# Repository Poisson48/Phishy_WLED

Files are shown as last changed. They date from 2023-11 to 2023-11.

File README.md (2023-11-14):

Phishy_WLED is a simple board to drive LED with the help of WLED software. It's based on esp32, it's fully open-source and i will probably sell some boards on etsy soon.

## Features
- RGBWWW LED strip support
- WS2182B ( or any ws18 someting ) LED strip support
- input from 5V to 60V
- pulled up inputs

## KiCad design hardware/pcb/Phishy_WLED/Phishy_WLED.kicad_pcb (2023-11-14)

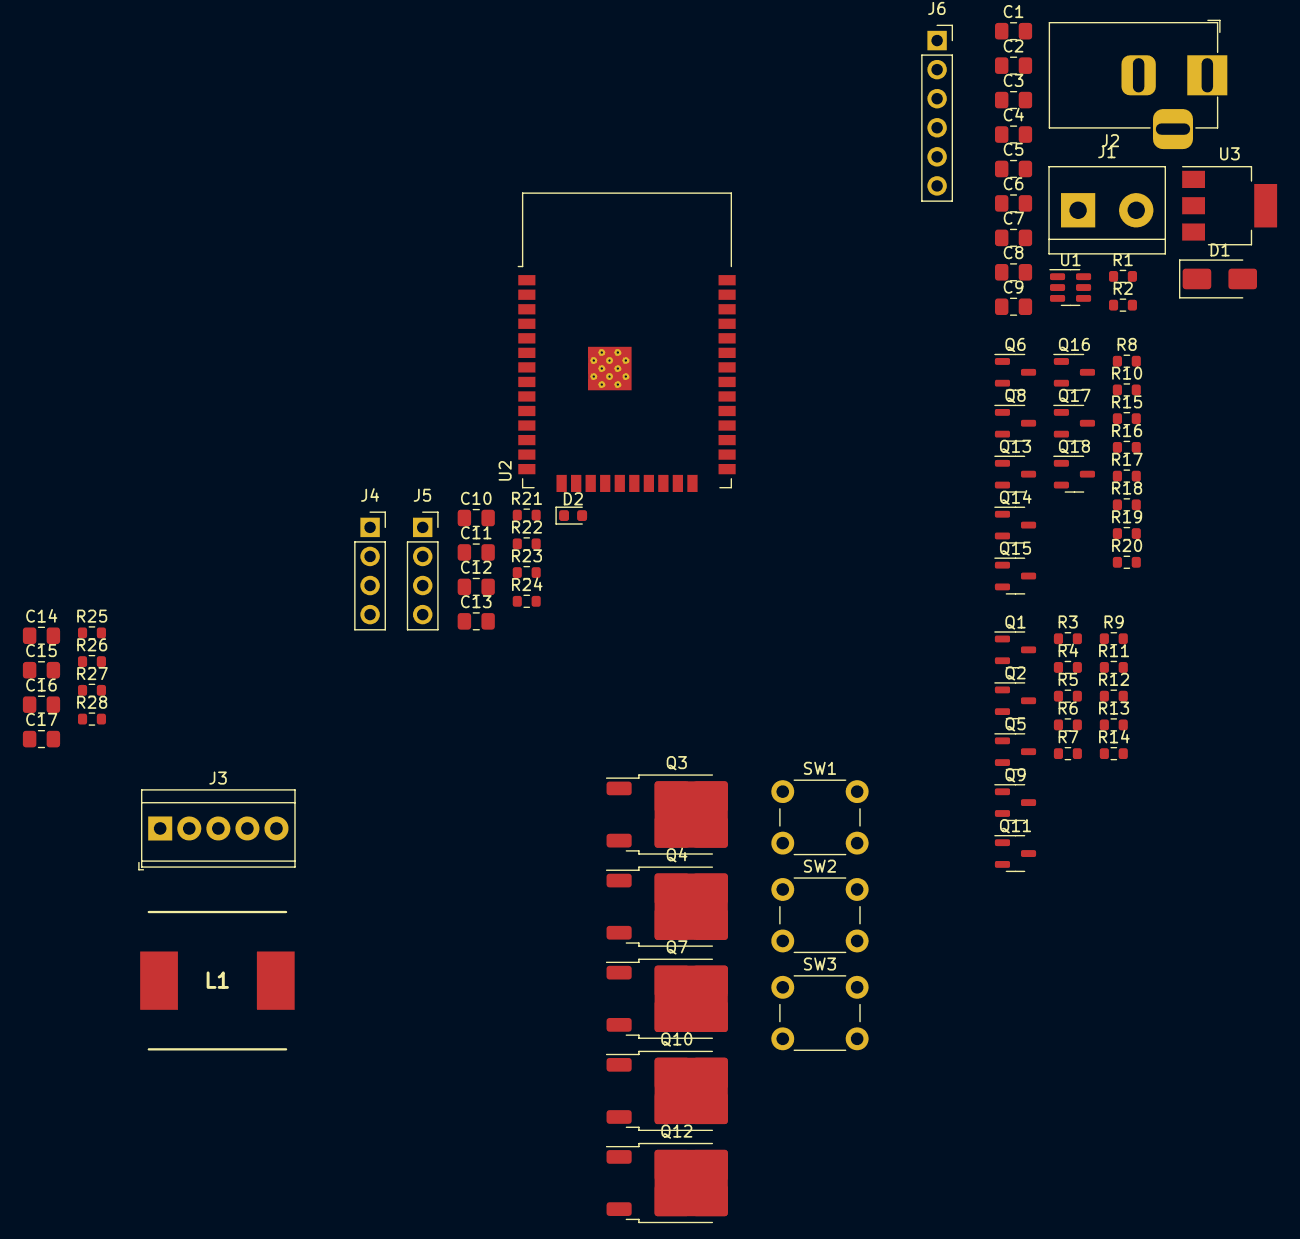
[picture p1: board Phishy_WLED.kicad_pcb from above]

Board: 2 copper layers, 78 parts (0 on the bottom side), 54 nets, no tracks yet.

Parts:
C1, C3, C5, C6, C8, C10, C13, C14, C15, C16, C17: 100nF; C_0805_2012Metric_Pad1.18x1.45mm_HandSolder
C2, C4, C7, C9, C11, C12: 10uF; C_0805_2012Metric_Pad1.18x1.45mm_HandSolder
D1: D_Schottky; D_SMA
D2: LED; LED_0603_1608Metric
J1: Screw_Terminal_01x02; TerminalBlock_bornier-2_P5.08mm
J2: Barrel_Jack_Switch; BarrelJack_Horizontal
J3: Screw_Terminal_01x05; TerminalBlock_TE_282834-5_1x05_P2.54mm_Horizontal
J4, J5: Screw_Terminal_01x04; PinSocket_1x04_P2.54mm_Vertical
J6: Conn_01x06; PinSocket_1x06_P2.54mm_Vertical
L1: 22uH; INDPM120120X800N
Q1, Q2, Q5, Q6, Q8, Q9, Q11, Q15, Q16: 2N7002L; SOT-23-3
Q3, Q4, Q7, Q10, Q12: IRFR1205TRPBF; TO-252-2
Q13, Q14, Q17, Q18: BSS138; SOT-23-3
R1, R2: R; R_0603_1608Metric
R3, R4, R7, R8, R11, R13, R15, R17, R18, R21, R22, R24, R25, R26, R27, R28: 10k; R_0603_1608Metric
R5, R6, R9, R10, R12, R14, R16, R19, R20, R23: 1k; R_0603_1608Metric
SW1, SW2, SW3: SW_Push; SW_PUSH_6mm_H5mm
U1: LMR16006YQ; SOT-23-6
U2: ESP32-WROOM-32D
U3: LM7805MP; SOT-223-3_TabPin2

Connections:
+3.3V: C4.1, C5.1, C10.1, C11.1, J6.3, L1.2, R1.1, R21.2, R22.2, R24.2, R25.2, R26.2, R27.2, R28.2, U2.2 (VDD)
+5V: C8.1, C9.1, R10.2, R16.2, R19.2, R20.2, U3.3 (OUT)
/drivers/in_B: R7.1, U2.28 (IO17)
/drivers/in_G: R4.1, U2.27 (IO16)
/drivers/in_R: R3.1, U2.16 (IO13)
/drivers/in_W: R11.1, U2.30 (IO18)
/drivers/in_WW: R13.1, U2.31 (IO19)
/drivers/out_B: J3.3, Q7.2 (D)
/drivers/out_G: J3.2, Q4.2 (D)
/drivers/out_R: J3.1, Q3.2 (D)
/drivers/out_W: J3.4, Q10.2 (D)
/drivers/out_WW: J3.5, Q12.2 (D)
/pulls_ups/pull_input_ext_1: C14.1, J5.1, R25.1, U2.11 (IO26)
/pulls_ups/pull_input_ext_2: C15.1, J5.2, R26.1, U2.12 (IO27)
/pulls_ups/pull_input_ext_3: C16.1, J5.3, R27.1, U2.8 (IO32)
/pulls_ups/pull_input_ext_4: C17.1, J5.4, R28.1, U2.9 (IO33)
/ws28xx_LEDs/in_DATA_1: R8.1, U2.33 (IO21)
/ws28xx_LEDs/in_DATA_2: R15.1, U2.36 (IO22)
/ws28xx_LEDs/in_DATA_3: R17.1, U2.37 (IO23)
/ws28xx_LEDs/in_DATA_4: R18.1, U2.10 (IO25)
/ws28xx_LEDs/out_DATA_1: J4.1, Q13.3 (D)
/ws28xx_LEDs/out_DATA_2: J4.2, Q14.3 (D)
/ws28xx_LEDs/out_DATA_3: J4.3, Q17.3 (D)
/ws28xx_LEDs/out_DATA_4: J4.4, Q18.3 (D)
EN: C12.1, J6.5, R21.1, SW2.2, U2.3 (EN)
unnamed: C3.2, D1.1 (K), L1.1, U1.6 (SW)
unnamed: D2.2 (A), R23.2
unnamed: Q1.2 (B), R3.2
unnamed: Q1.1 (C), Q3.1 (G), R5.1
unnamed: Q2.2 (B), R4.2
unnamed: Q2.1 (C), Q4.1 (G), R6.1
unnamed: Q5.2 (B), R7.2
unnamed: Q5.1 (C), Q7.1 (G), R9.1
unnamed: Q6.2 (B), R8.2
unnamed: Q8.2 (B), R15.2
unnamed: Q9.2 (B), R11.2
unnamed: Q9.1 (C), Q10.1 (G), R12.1
unnamed: Q11.2 (B), R13.2
unnamed: Q11.1 (C), Q12.1 (G), R14.1
unnamed: Q6.1 (C), Q13.1 (G), R10.1
unnamed: Q8.1 (C), Q14.1 (G), R16.1
unnamed: Q15.2 (B), R17.2
unnamed: Q15.1 (C), Q17.1 (G), R19.1
unnamed: Q16.2 (B), R18.2
unnamed: Q16.1 (C), Q18.1 (G), R20.1
unnamed: C3.1, U1.1 (CB)
unnamed: R1.2, R2.1, U1.3 (FB)
unnamed: R22.1, SW1.1, U2.25 (IO0)
unnamed: R23.1, U2.24 (IO2)
unnamed: C13.1, R24.1, SW3.1, U2.26 (IO4)
RST: C1.2, C2.2, C4.2, C5.2, C6.2, C7.2, C8.2, C9.2, C10.2, C11.2, C12.2, C13.2, C14.2, C15.2, C16.2, C17.2, D1.2 (A), D2.1 (K), J1.2, J2.2, J2.3, J6.4, J6.6, Q1.3 (E), Q2.3 (E), Q3.3 (S), Q4.3 (S), Q5.3 (E), Q6.3 (E), Q7.3 (S), Q8.3 (E), Q9.3 (E), Q10.3 (S), Q11.3 (E), Q12.3 (S), Q13.2 (S), Q14.2 (S), Q15.3 (E), Q16.3 (E), Q17.2 (S), Q18.2 (S), R2.2, SW1.2, SW2.1, SW3.2, U1.2 (GND), U2.1 (GND), U2.15 (GND), U2.38 (GND), U2.39 (GND), U3.2 (GND)
RX: J6.2, U2.34 (RXD0/IO3)
TX: J6.1, U2.35 (TXD0/IO1)
VCC: C1.1, C2.1, C6.1, C7.1, J1.1, J2.1, R5.2, R6.2, R9.2, R12.2, R14.2, U1.5 (VIN), U3.1 (IN)

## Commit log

2023-11-14 basic schematic
    the basic schematic is finished, need to add the footprints and begin the placement
    [Phishy_WLED.kicad_pcb, Phishy_WLED.kicad_sch, alim.kicad_sch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]
2023-11-14 footprints added !
    all the footprints are here
    [Phishy_WLED.kicad_pcb, Phishy_WLED.kicad_sch, alim.kicad_sch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]
